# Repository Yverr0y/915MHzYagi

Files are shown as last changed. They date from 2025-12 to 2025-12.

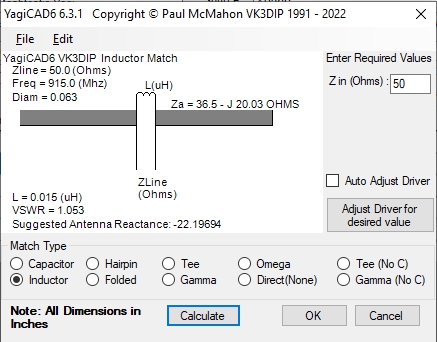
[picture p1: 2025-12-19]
Inductive Match Information.jpg

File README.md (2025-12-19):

# 915 MHz Window-Mounted Yagi Antenna for Meshtastic



A directional Yagi antenna optimized for the 915 MHz US Meshtastic band, designed for easy window mounting to direct RF outward and improve range over stock antennas.

## Inspiration

This project was inspired by a [Hackaday article from February 2025](https://hackaday.com/2025/02/20/diy-yagi-antenna-sends-lora-signals-farther/) featuring a handheld Yagi antenna for 868 MHz (European Meshtastic/LoRa) by [taste_the_code], which demonstrated impressive range improvements.

Members of the Gloucester County Amateur Radio Club (GCARC, New Jersey) saw the potential and adapted the design for the 915 MHz US band, converting it into a window-mounted version to focus signal outside buildings for better connectivity with distant nodes.

## Design Features

- Retuned elements and boom for 915 MHz operation.
- 3D-printed boom with integrated mounts for suction cups (indoor or outdoor window placement).
- Added matching inductor for improved impedance match (~50 Ω).
- Directional pattern with measured front-to-back ratio of ~7.7 dB.
- VSWR ~1.8:1 (tested with modeling software and Vector Network Analyzers).
- Significantly better real-world performance than stock Meshtastic antennas in preliminary field tests.

Project lead: Chris Prioli (AD2CS), who handled redesign, 3D modeling, matching improvements, and assembly instructions.

In early December 2025, GCARC members built ~24 units in a group session, with encouraging range results.

## Why Build in Groups?

Materials (wire elements, coax, suction cups, etc.) are often sold in bulk quantities, making group builds the most cost-effective and practical approach. We encourage other Meshtastic communities and amateur radio clubs to organize similar build parties to equip local users!

## License

Copyright © 2025 Gloucester County Amateur Radio Club

This open hardware design is licensed under the [CERN Open Hardware Licence Version 2 - Permissive (CERN-OHL-P v2)](https://cern.ch/cern-ohl/p/v2).

See the `LICENSE` file for details.

## Contributing

Contributions welcome! Fork the repo, make improvements, and submit pull requests.

## Acknowledgments

- Original inspiration: [taste_the_code]'s 868 MHz Yagi (via Hackaday).
- GCARC team for building and testing.

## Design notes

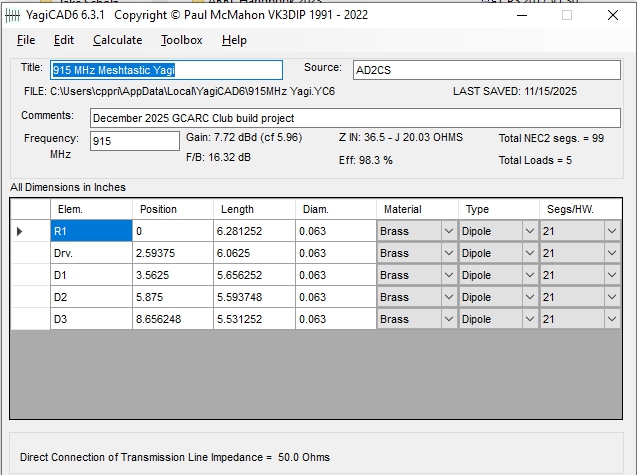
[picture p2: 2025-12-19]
Basic Specifications.jpg

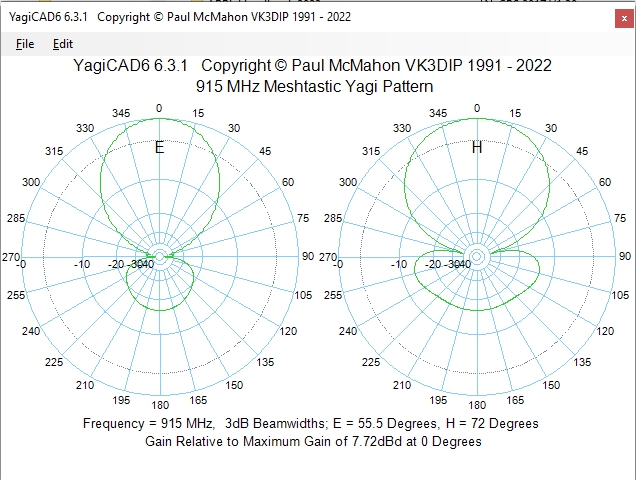
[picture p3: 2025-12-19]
Radiation Patterns - Elevation and Azimuthal.jpg

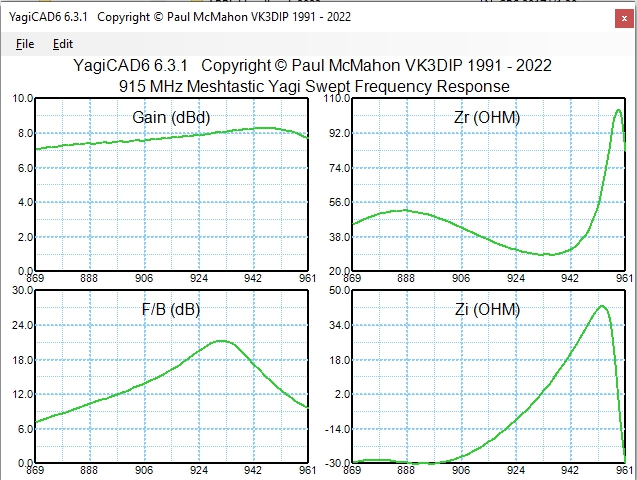
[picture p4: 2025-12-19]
Overall Gain, Front-Back Gain, and Impedance Graphs.jpg

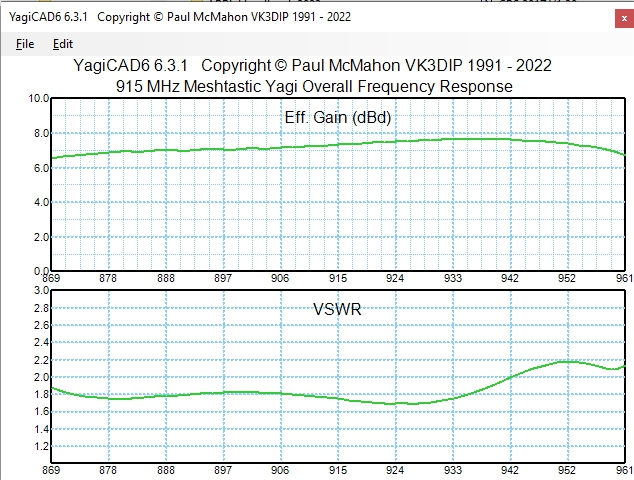
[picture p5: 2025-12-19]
Effective Gain & VSWR Graphs.jpg

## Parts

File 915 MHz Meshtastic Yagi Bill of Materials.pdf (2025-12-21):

Brass Rods | Source URL | Vendor | Pkg Info | Notes
Coaxial Cable | https://www.amazon.com/dp/B07SZ24TQD | Amazon | pkg/2 pcs | yields 4 cables - cut each whole length in half
Brass Rods | https://www.amazon.com/dp/B09VN6K745 | Amazon | pkg/30 pcs | each antenna requires 3 rods, but can be cut in less if cutting for quantity build
Suction Cup | https://www.amazon.com/dp/B0BCKCKQ33 | Amazon | pkg/12 pcs | each antenna uses one piece
Nylon Screw | https://www.digikey.com/en/products/detail/essentra-components/011032p200/9677317 | Digikey | per piece | each antenna uses one piece
Wing Nut | https://www.digikey.com/en/products/detail/essentra-components/0601032wn/10243310 | Digikey | per piece | each antenna uses one piece
Flat Washers | https://www.amazon.com/dp/B0DC6PYKT6 | Amazon | pkg/200 pcs | each antenna uses 2 pieces
Lock Washers | https://www.amazon.com/dp/B0714PXB3G | Amazon | pkg/100 pcs | each antenna uses 2 pieces

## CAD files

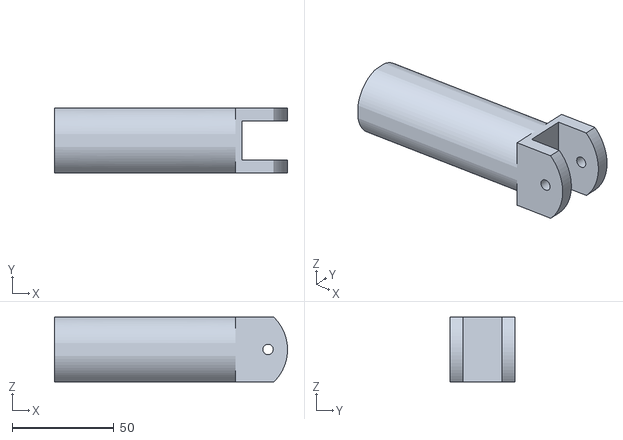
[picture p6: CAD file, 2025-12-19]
Handle v3.stl
114.3 x 31.8 x 31.8

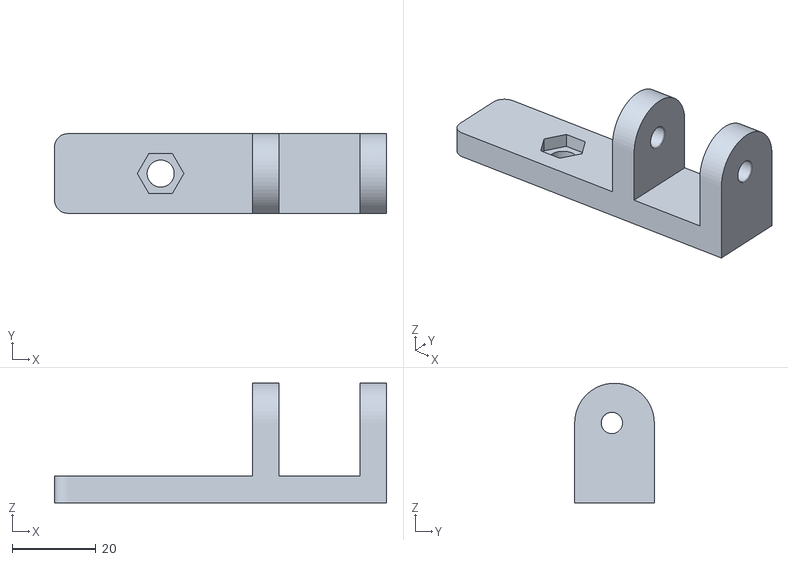
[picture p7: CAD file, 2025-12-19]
WIndow Bracket v4.stl
79.4 x 19.1 x 28.6

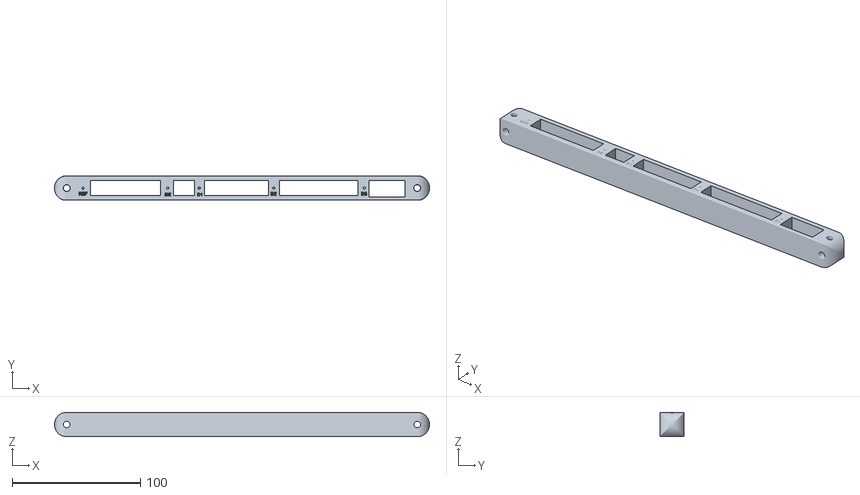
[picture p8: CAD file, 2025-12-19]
Boom v5.stl
292.1 x 19.1 x 19.0

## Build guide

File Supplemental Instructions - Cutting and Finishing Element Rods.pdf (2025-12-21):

# Supplemental Instructions for 915 MHz Meshtastic Yagi Antenna Build

While the basic instruction set for this build is complete as far as it goes, it does not really go far enough. This is due to the fact that the instruction set was developed and written as applicable to the assembly of the antenna from the kits that were provided to the GCARC Club members involved in the original build event. Those kits included pre-cut and finished element rods for the antenna. Thus, that instruction set did not reference cutting and finishing the element rods in any manner whatsoever, and in fact, the instructions never actually identified the specific lengths of the elements. While that data can be gleaned from a careful read of the YagiCad® screen capture provided, which shows the element lengths and positions, it was decided to develop and provide these specific element preparation instructions.
Based on the lengths of the individual element rods, a total of three of the twelve-inch brass rod stock recommended for this build will be needed if constructing a single antenna. If constructing multiple antennas (or preparing kits for such a build), it is possible to use less than three full rods for a single antenna, resulting in less waste rod stock. We will discuss this concept more in depth later on.

Table 1 - Element lengths and positions
Element ID | Element Name | Element Location | Element Length | Qty
REF | Reflector | 0.00” | 6.28125” (6-9/32”) | 1
DE* | Driven Element | 2.59375” (2-19/32”) | 3.03125” (3-1/32”)
2 DE* | Driven Element | 2.59375” (2-19/32”) | 3.03125” (3-1/32”)
D1 | Director #1 | 3.5625” (3-9/16”) | 5.65625” (5-21/32”) | 1
D2 | Director #2 | 5.875” (5-7/8”) | 5.59375” (5-19/32”) | 1
D3 | Director #3 | 8.65625” (8-21/32”) | 5.53125” (5-17/32”) | 1
*DE is duplicated due to the split nature of the driven element. Two identical element rods are used, located at the same relative distance from the reflector element, one on either side of the boom and with an insulator between them.
Table 1 shows the element lengths and positions on the boom. The boom element locations are pre-indicated during the 3-D print of the boom, so these locations are provided purely for reference purposes – you will not need to use these numbers.
The preparation of the element rods requires the use of a strong cutting pliers, preferably end-cutting pliers. In addition, a means must be available to square off the end of the element rod where the rod was cut. This is best done with a Dremel® tool with a cut-off wheel in its tool collet. While it can also be done with a good file, that is a very tedious and dirty job. An ultrafine-point Sharpie® marker will be needed for marking the rod stock during measurement, and an accurate means of measuring to the nearest thirty-second of an inch is needed. I recommend a steel rule such as the Mr. Pen Steel Rulers offered by Amazon (https://www.amazon.com/gp/product/B07ZS4JSQP) for a very reasonable price. These rulers have the advantage of clear and accurate markings with no offset of the “zero” position. This means that you can simply line up one end of the rod stock with the end of the ruler and go from there.
Once all of the required equipment is at hand, start by marking out the element lengths on the rod stock as follows:
- on the first rod, measure and mark 6-9/32” from one end of the rod, and then measure and mark 5-17/32” from the opposite end of the rod, and set that rod aside;
- on the second rod, measure and mark 5-21/32” from one end of the rod, and then measure and mark 5-19/32” from the opposite end of the rod, and set that rod aside; and
- on the third rod, measure and mark 3-1/32” from one end of the rod, and then measure and mark 3-1/32” from the opposite end of the rod, and set that rod aside. The next step is to rough-cut the element rods, based upon the marks that were just made. If the above instructions were followed properly, each rough-cut rod will end up having one square finished end after the rough cuts are made.
Using the end-cutting pliers, cut each piece of rod stock about a thirty-second of an inch away from the measured mark towards the center of the rod. This means that you will be making the first cut between the two marks on the rod stock, and then the second cut will be made between the remaining measured mark and the cut end of the rod stock. Once all three pieces of rod stock have been cut near each of the measured marks, the yield will be six element rods which will each have one finished end, one rough end, and each will be about a thirty-second of an inch longer than its measured and marked length. Finish each element rod by grinding or filing off the rough-cut end, bringing the cut to a clean square finish and the element rod to its specified finished length. Lay the rod against the ruler periodically as you grind or file it to ensure compliance with the length requirement for the element rod on which you are working at that time.
Finally, dress of any flash that may be “mushrooming” the cut end of the rod to give a nice clean and round element rod end that will fit properly into the hole on the boom. This will complete the preparation of the element rods from three twelve-inch lengths of brass rod stock, for a single antenna construction project.
If you are in the position of needing to prepare element rods for multiple antennas to be built, for example, if you are preparing kits for future use in building the antenna in quantity, some reduction in rod stock waste can be achieved. In this case, you would be laying out and cutting the element rods for three antennas using only eight lengths of rod stock instead of nine lengths as would be used in the single-antenna process.

Begin by measuring and marking three sets of reflector and director (or parasitic) element rods in the same manner as was described in the single-antenna procedure. That means that you will be measuring and marking out the element lengths on the rod stock as follows:
- on the first rod, measure and mark 6-9/32” from one end of the rod, and then measure and mark 5-17/32” from the opposite end of the rod, and set that rod aside; and
- on the second rod, measure and mark 5-21/32” from one end of the rod, and then measure and mark 5-19/32” from the opposite end of the rod, and set that rod aside.
Repeat that measure and mark sequence to get three sets of rods, which yields four elements each for three antennas. Rough-cut and then finish these element rods as described previously.
Next, measure and mark two lengths of rod stock at four-inch intervals, effectively marking the rod stock in thirds. Cut these rod segments at each of the marks, which will give you six four-inch rods segments. Four of those rod segments will be finished at one end, while the remaining two rod segments – the ones cut from the centers of the rod stock lengths – will be rough-cut on both ends. Using the Dremel® tool or the file, dress and finish one end of each of the two rods that have both ends cut.
Continue by measuring and marking, working from the finished end of the rod segments, 3-1/32” from the finished end of each of the six four-inch rod segments. Then, rough-cut those rod segments at about 1/32” past the mark towards the cut end of the rod segment. Finally, using the tool of your choice, grind or file the rod segments to their finished element rod length of 3-1/32” as was done with the parasitic elements earlier. This completes the element rod preparation procedure when multiple antennas are being prepped, or when kits are being assembled. Note that a standard drinking straw makes a great storage tube for the finished element rods. Fold over and staple one end of the drinking straw, slide the element rods into the straw, and then fold over and staple the second end of the straw closed. This keeps the element rods together and prevents them from poking their way out of a plastic bag that may be used to contain all of the parts that comprise an antenna kit.

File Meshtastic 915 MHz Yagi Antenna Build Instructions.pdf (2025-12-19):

## Meshtastic 915 MHz Yagi Antenna Build Instructions

Thank you for participating in the GCARC 915 MHz Yagi antenna group build program. While this is an extremely simple build, it could be confusing to anyone who does not fully understand the process. To help avoid any such confusion, we have put together this set of build instructions. Follow the step-by-step procedure below to achieve a proper build of the antenna kit.
1. Verify that all of the required parts are on hand, as listed below:
a. antenna boom;
b. antenna handle;
c. antenna window bracket with an acorn nut installed;
d. suction cup with a mounting stud attached;
e. set of pre-cut brass rod elements (six pieces, packaged inside plastic tube);
f. RG-174 coaxial cable 18” long with male SMA connector on one end;
g. two (2) small (4”) zip ties;
h. four-inch length of 22AWG solid wire (various colors);
i. SMA thumb wrench;
j. 10-32 nylon fillister head machine screw;
k. 10-32 nylon wing nut;
l. two (2) #10 stainless steel flat washers; and
m. two (2) #10 externally-toothed lock washers.
2. Verify that the required supplies and equipment are on hand, as listed below:
a. soldering station with rosin-core solder;
b. 99.9% isopropyl alcohol (IPA);
c. paper towel(s);
d. cyanoacrylate (CA) glue;
e. accelerator for CA glue;
f. razor knife;
g. Sharpie® marker;
h. ruler or measuring tape;
i. push-pin or pointed tweezer;
j. needle-nose pliers;
k. wire cutter and stripper;
l. NanoVNA; and
m. 915 MHz Meshtastic Node.
3. If not already done, remove the brass rod elements from the packing tube, and using a paper towel and some IPA, thoroughly clean each element rod of all film and residue that may be on the element rods.
4. Lay out the element rods in order of decreasing length, setting the two shortest (equal length) element rods aside.
5. Measure and mark the center of each of the long element rods.

6. Make another pair of marks on each element rod, making one exactly 7/16” on each side of the center mark. This will define an area 7/8” wide at the center of each element rod.
7. Examine the boom carefully, noting the markings adjacent to each of the small (1/16”) element holes in the boom. These markings are as follows:
a. REF – the reflector element;
b. DE – the driven element (this is where the two shortest but equal-length element rods will eventually be installed);
c. D1 – the first director element;
d. D2 – the second director element; and
e. D3 – the third director element.
8. Starting with the longest element rod at the REF hole and skipping the DE hole, working from the longest to the shortest of the long element rods, insert a rod into the REF hole (the longest element rod) and each of the D# holes (progressively shorter element rods), centering the boom between the paired marks on the element rods.
9. Verify that the element rods get shorter as you progress along the boom, starting at the REF end of the boom, and also that the DE hole is empty.
10. Working quickly, one by one slide each element out of its hole in the boom just until the center mark is visible, and apply a drop of CA glue to the element rod, and then immediately center the boom again accurately between the paired marks on the element rod, twisting the element rod as it is inserted.
11. After all four of the long element rods are glued and centered accurately, apply a small spray of CA glue accelerant to each of the element rods at the boom. This will cause the CA glue to completely set almost immediately.
12. Set the boom and elements aside for later use.
13. Locate the four-inch length of 22AWG solid wire from the parts kit.
14. Using the wire stripper, remove 1/2" of insulation from each end of the wire. SAVE ONE OF THE PIECES OF INSULATION THAT YOU REMOVE – IT WILL BE USED LATER!
15. Using the small end of the barrel of the Sharpie® marker as a spindle, form a singleturn loop in the center of the insulated portion of the wire, making a one-turn aircore inductor. The loop should be 1/4” in diameter with the leads extending straight out and opposite each other (in a straight line).
16. Apply a drop of CA glue to the inductor wire at the point where the wire crosses itself as it forms the loop.
17. Apply a bit of the CA glue accelerant to the inductor to quick-set the glue there.
18. Set the inductor aside for later use.
19. Locate the RG-174 coaxial cable.
20. Using the razor knife and working carefully so as not to cut the shield wire strands, remove 2-1/2” of outer jacket from the unfinished end of the cable.
21. Using the push pin, gently unbraid and comb out the shield wire strands, leaving them all parallel to the center conductor.

22. Once the shield wire strands are all separated and straightened, gather them all together and twist them tightly into a single bundle.
23. Using the wire stripper, carefully remove 1/2" of insulation from the coaxial cable center conductor. Work very carefully so as not to damage the center conductor wire strands.
24. Twist the center conductor wire strands together tightly.
25. Using the solder station, tin the twisted center conductor wire.
26. Using the solder station, tin the last 1/2" of the twisted shield wire.
27. Using the needle-nose pliers, bend a hook the size of the element rod into the end of each tinned segment of the coaxial cable wires.
28. Using the solder station, carefully solder the coaxial cable wire segments to the two short driven-element rods, attaching each of them about 1/2” from one end of each of the element rods, and allow the element rods to cool completely.
29. Locate the inductor that was set aside earlier.
30. Using the needle-nose pliers, bend a hook the size of the element rod into each stripped end of the inductor wire.
31. Using the solder station, carefully solder one end of the inductor wire to one of the driven-element rods, placing the inductor wire just outboard (towards the long end) of the element rod, and allow the element rod to cool completely.
32. Locate the piece of wire insulation (from the inductor wire) that you set aside earlier.
33. Cut off a small piece of this insulation, about 1/8” long.
34. Insert the 1/8” piece of insulation into the DE hole in the boom. Use the end of the push pin to push the insulation into the hole in the boom, pushing it about half-way through the boom.
35. Passing the looped inductor wire through the opening in the boom nearest the DE hole, insert one of the driven-element rods into the DE hole on each side of the boom and then position them so that each element rod is the same distance into the boom, and so that they meet in the middle with the insulation piece in between the ends of the element rods.
36. Solder the loose end of the inductor wire to the adjacent element rod immediately outboard of the coaxial cable wire attachment there, taking care not to let the coaxial cable wire separate from the element rod as you solder the inductor wire.
37. One at a time, slide the driven element rods out of the boom and apply a drop of CA glue to the end of the rod. Immediately insert the element rod back into its hole in the boom without disturbing the opposite element rod.
38. After both driven element rods have been glued, apply the CA glue accelerator spray to the boom and driven element rods to quick-set the glue.
39. Dress the coaxial cable along the boom adjacent to the DE hole in the boom, and secure it there with both of the 4” zip ties provided. DO NOT RUN THE FULL LENGTH OF THE CABLE ALONG THE BOOM – LET IT HANG FREELY AFTER SECURING IT TO THE BOOM NEAR ITS ATTACHMENT TO THE DRIVEN ELEMENT RODS. The zip ties should pass through the opening in the boom, and should be pushed all the way towards and against the boom opening wall adjacent to the DE hole. The purpose of the zip ties is to support the coaxial cable and to take its weight off of the solder joints.
40. Locate the suction cup and the window bracket.
41. Thread the mounting stud on the suction cup into the acorn nut that is installed into the window bracket.
42. Locate the nylon machine screw, the nylon wing nut, the two #10 flat washers, and the two #10 externally-toothed lock washers.
43. Place one of the externally-toothed lock washers onto the nylon machine screw, and then place one of the flat washers onto the screw. The lock washer should be directly against the head of the screw.
44. Insert the boom into the yoke of the window bracket, being sure to position the boom so that the element rods will be parallel to the axis of the nylon machine screw once the screw is installed.
45. Insert the nylon machine screw through the ears of the window bracket yoke and also through the hole in the end of the boom, which will be aligned with the yoke ear holes.
46. Place the second flat washer onto the nylon machine screw and against the second ear of the window bracket yoke.
47. Place the second lock washer onto the nylon machine screw and against the second flat washer just installed.
48. Thread the nylon wing nut onto the nylon machine screw, taking care not to crossthread the wing nut.
49. Tighten the nylon wing nut sufficiently to clamp the boom in the window bracket yoke. DO NOT OVERTIGHTEN, STRIP, STRETCH, OR BREAK THE NYLON WING NUT AND/OR MACHINE SCREW.
This completes the assembly of the antenna and its window bracket. Should you choose to use the antenna on the handle instead of on the window bracket, simply install the handle in place of the window bracket, being sure to install the hardware in the same manner. The flat washers must go against the yoke ears of either the handle or the window bracket, whichever is in use.
The antenna can now be tested using your NanoVNA and also by connection of the antenna to the 915 MHz Meshtastic node and placing the node into operation.

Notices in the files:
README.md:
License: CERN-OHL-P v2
